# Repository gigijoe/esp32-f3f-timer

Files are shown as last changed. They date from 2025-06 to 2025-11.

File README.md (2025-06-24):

# ESP32 F3F Timer by Steve Chang
This is a open source F3F timer base on ESP32 MCU. It supports wire / wifi / CRSF Base A/B trigger input.
Voice report & external buzzer supoort for minimize delay of audio report.

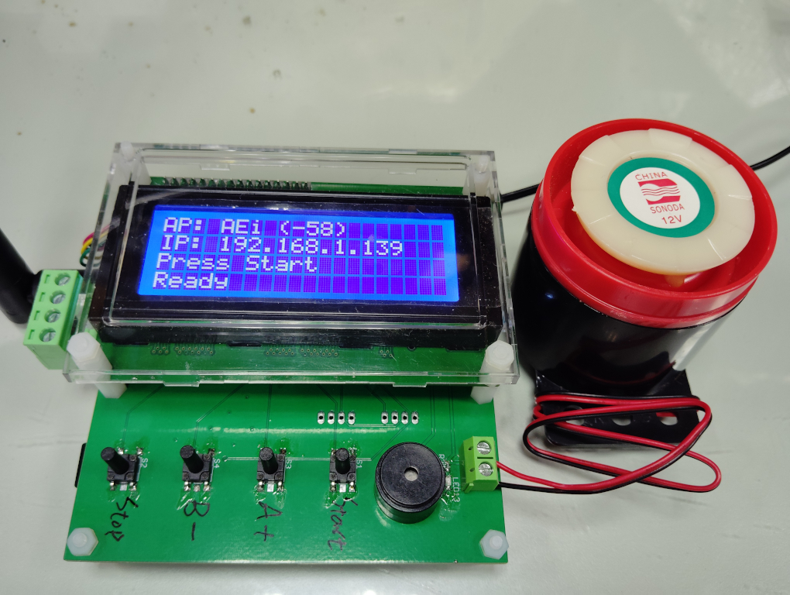
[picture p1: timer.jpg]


### Hardware
- ESP32 MCU
- Micro SD slot
- PCM5102A audio
- Base A/B wire input
- Wifi antenna
- 2004A Mono LCD display
- Internal buzzer / external buzzer
- DC jack 12V
- 4 buttons

### Software
- F3F timer function (Start / Stop / finish / time report)
- Voice report
- Buzzer sound when Base A/B trigger
- Wifi station
- Support wifi multicast trigger from Base A/B
- Support wire Base A/B trigger
- Support CRSF Base A/B trigger
- LCD display Wifi status / timer / volume adjusted / Base A/B trigger

### Buttons
- [ Stop ] / [ B- ] / [ A+ ] / [ Start ] Buttons

## Idle State
- Wifi Status Page
- Last Record Page
- F3F Mode Page - F3F Training / F3F Competition mode switch by [ A+ ] Button
- Wind Data Page
- Volume Page - Adjust volume by [ A+ ] / [ B- ] Buttons

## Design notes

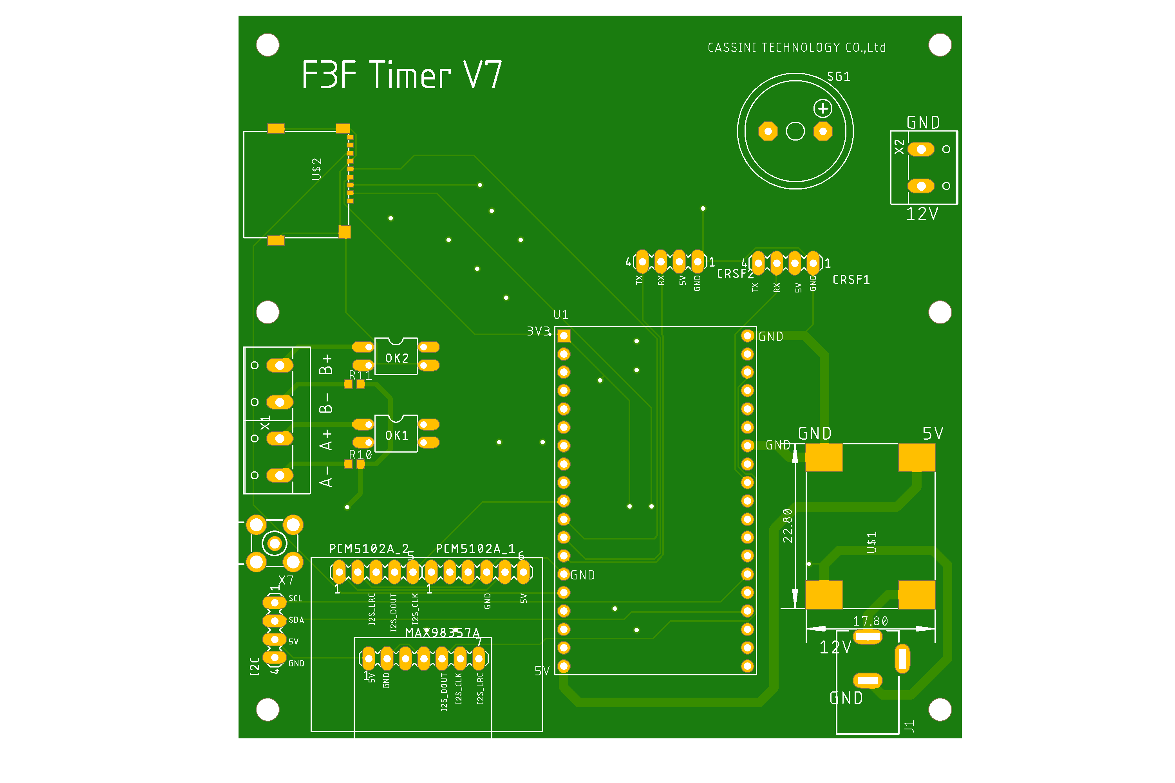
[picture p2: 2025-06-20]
hardware/F3F-TIMER-V7/7.x/top.png

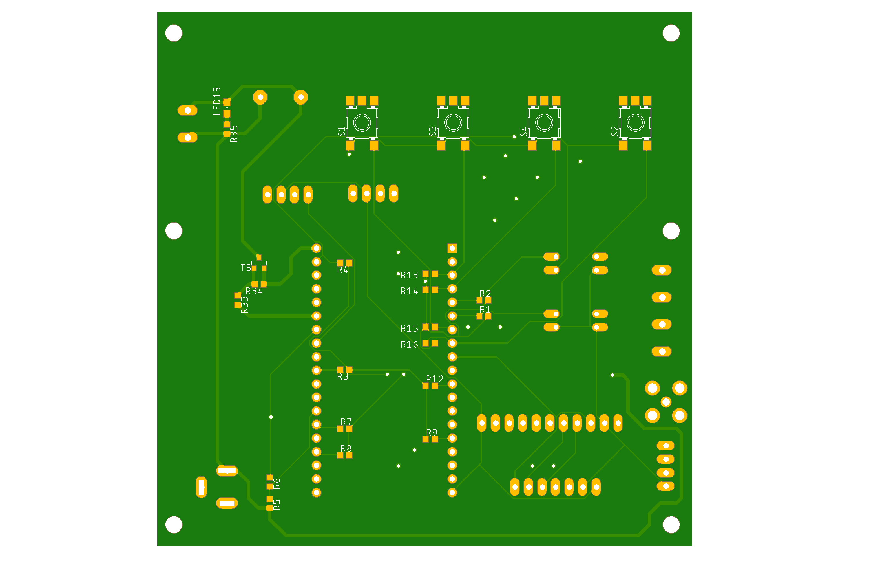
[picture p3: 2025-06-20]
hardware/F3F-TIMER-V7/7.x/bottom.png

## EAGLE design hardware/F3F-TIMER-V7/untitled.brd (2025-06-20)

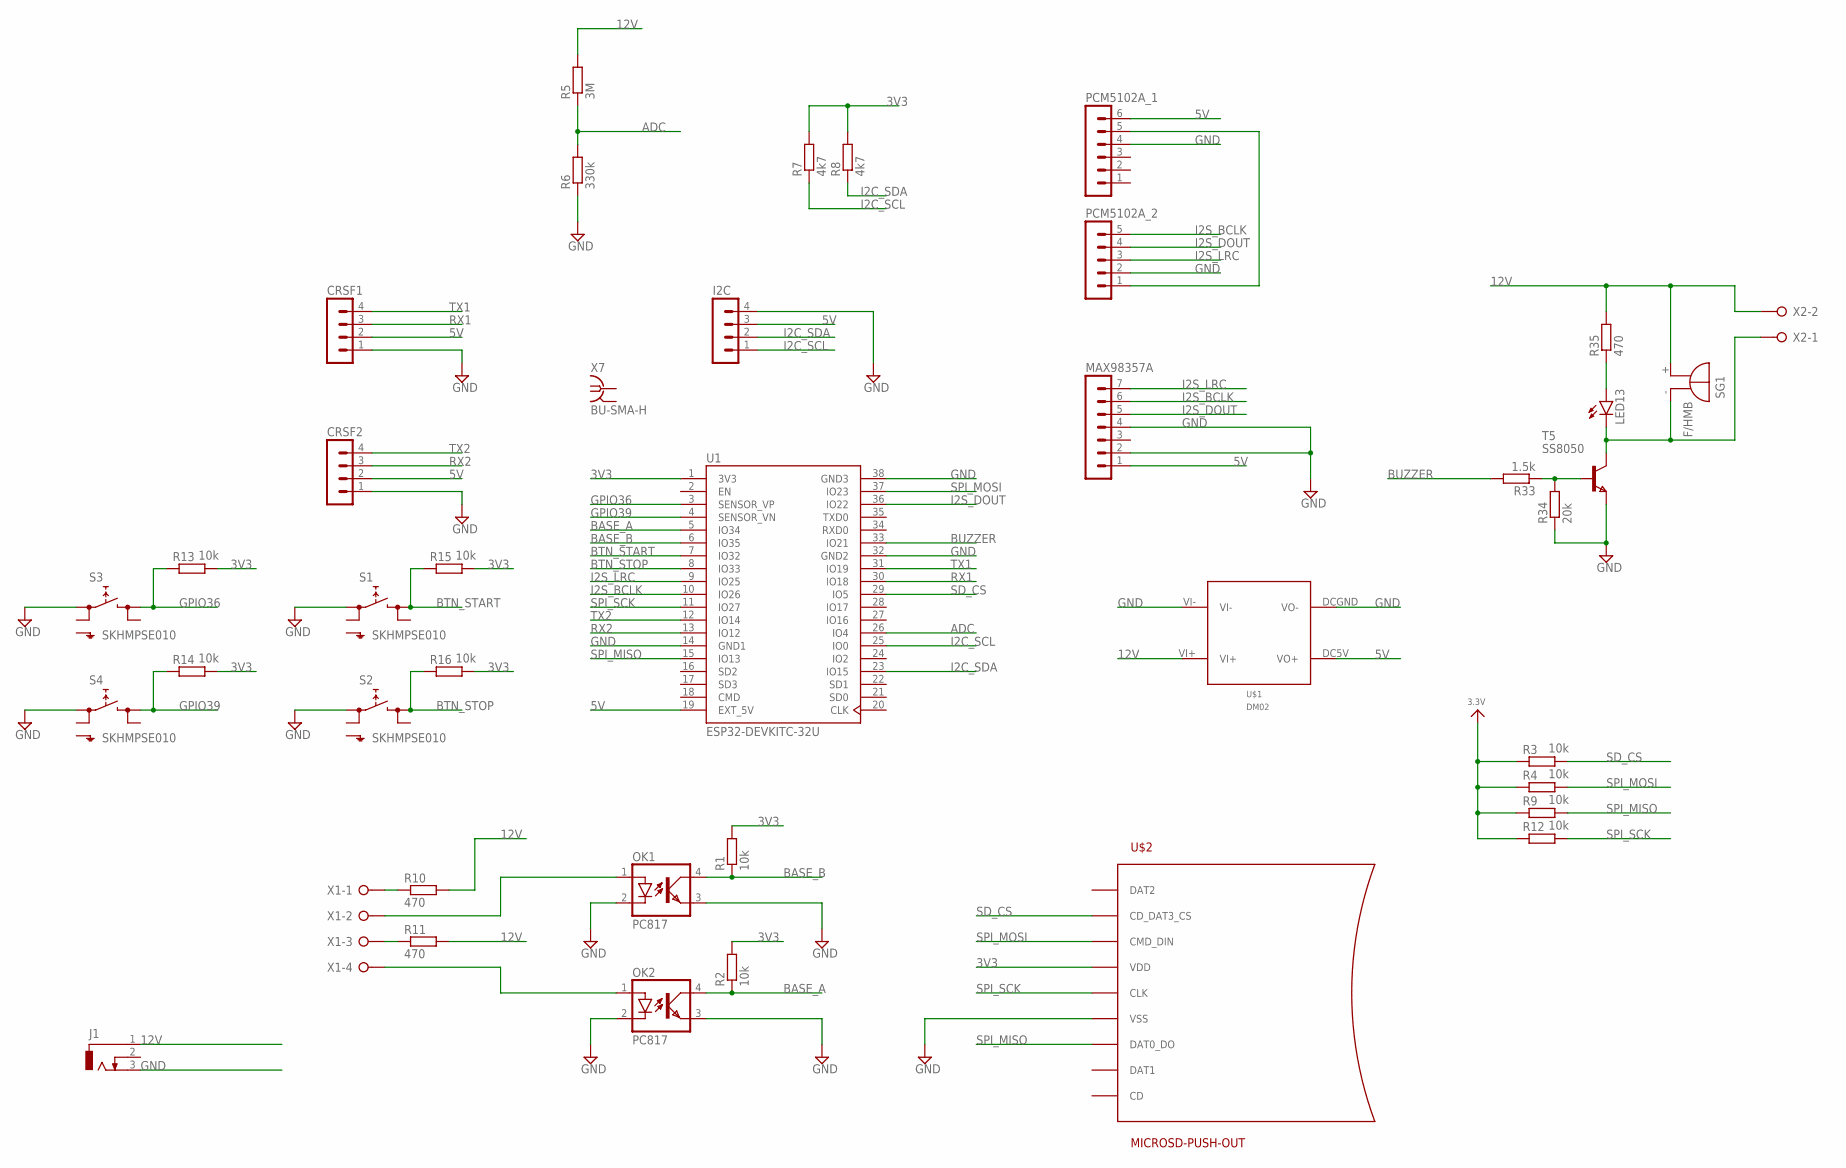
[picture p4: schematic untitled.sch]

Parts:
CRSF1, CRSF2: MA04-1
I2C: MA04-1
J1: DCJ0303
LED13: LEDCHIPLED_0805; CHIPLED_0805
MAX98357A: MA07-1
OK1, OK2: PC817; DIL04
PCM5102A_1: MA06-1
PCM5102A_2: MA05-1
R1, R2, R3, R4, R9, R12, R13, R14, R15, R16: 10k; R0603
R5: 3M; R0603
R6: 330k; R0603
R7, R8: 4k7; R0603
R10, R11, R35: 470; R0603
R33: 1.5k; R0603
R34: 20k; R0603
S1, S2, S3, S4: SKHMPSE010; SKHMPXE010
SG1: F/HMB
T5: SS8050; SOT-23
U1: ESP32-DEVKITC-32U; MODULE_ESP32-DEVKITC-32U
U$1: DM02
U$2: MICROSD-PUSH-OUT
X1: W237-04P; W237-4P
X2: W237-02P; W237-132
X7: BU-SMA-H

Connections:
3.3V: R3.1, R4.1, R9.1, R12.1
3V3: R1.2, R2.2, R7.2, R8.2, R13.2, R14.2, R15.2, R16.2, U1.1 (3V3), U$2.4 (VDD)
5V: CRSF1.2, CRSF2.2, I2C.3, MAX98357A.1, PCM5102A_1.6, U1.19 (EXT_5V), U$1.DC5V (VO+)
12V: J1.1, R5.2, R10.2, R11.2, R35.2, SG1.+, U$1.VI+, X2.2
ADC: R5.1, R6.2, U1.26 (IO4)
BASE_A: OK2.4 (COL), R2.1, U1.5 (IO34)
BASE_B: OK1.4 (COL), R1.1, U1.6 (IO35)
BTN_START: R15.1, S1.3 (2.1), U1.7 (IO32)
BTN_STOP: R16.1, S2.3 (2.1), U1.8 (IO33)
BUZZER: R33.2, U1.33 (IO21)
GND: CRSF1.1, CRSF2.1, I2C.4, J1.3, MAX98357A.2, MAX98357A.4, OK1.2 (C), OK1.3 (EMIT), OK2.2 (C), OK2.3 (EMIT), PCM5102A_1.4, PCM5102A_2.2, R6.1, R34.1, S1.1 (1.1), S2.1 (1.1), S3.1 (1.1), S4.1 (1.1), T5.2 (E), U1.14 (GND1), U1.32 (GND2), U1.38 (GND3), U$1.DCGND (VO-), U$1.VI-, U$2.6 (VSS), U$2.G1 (VSS), U$2.G2 (VSS), U$2.G3 (VSS), U$2.G4 (VSS)
GPIO36: R13.1, S3.3 (2.1), U1.3 (SENSOR_VP)
GPIO39: R14.1, S4.3 (2.1), U1.4 (SENSOR_VN)
I2C_SCL: I2C.1, R7.1, U1.25 (IO0)
I2C_SDA: I2C.2, R8.1, U1.23 (IO15)
I2S_BCLK: MAX98357A.6, PCM5102A_2.5, U1.10 (IO26)
I2S_DOUT: MAX98357A.5, PCM5102A_2.4, U1.36 (IO22)
I2S_LRC: MAX98357A.7, PCM5102A_2.3, U1.9 (IO25)
unnamed: OK1.1 (A), X1.2
unnamed: OK2.1 (A), X1.4
unnamed: PCM5102A_1.5, PCM5102A_2.1
unnamed: R10.1, X1.1
unnamed: R11.1, X1.3
unnamed: R33.1, R34.2, T5.3 (B)
unnamed: LED13.A, R35.1
unnamed: LED13.C, SG1.-, T5.1 (C), X2.1
RX1: CRSF1.3, U1.30 (IO18)
RX2: CRSF2.3, U1.13 (IO12)
SD_CS: R3.2, U1.29 (IO5), U$2.2 (CD_DAT3_CS)
SPI_MISO: R9.2, U1.15 (IO13), U$2.7 (DAT0_DO)
SPI_MOSI: R4.2, U1.37 (IO23), U$2.3 (CMD_DIN)
SPI_SCK: R12.2, U1.11 (IO27), U$2.5 (CLK)
TX1: CRSF1.4, U1.31 (IO19)
TX2: CRSF2.4, U1.12 (IO14)

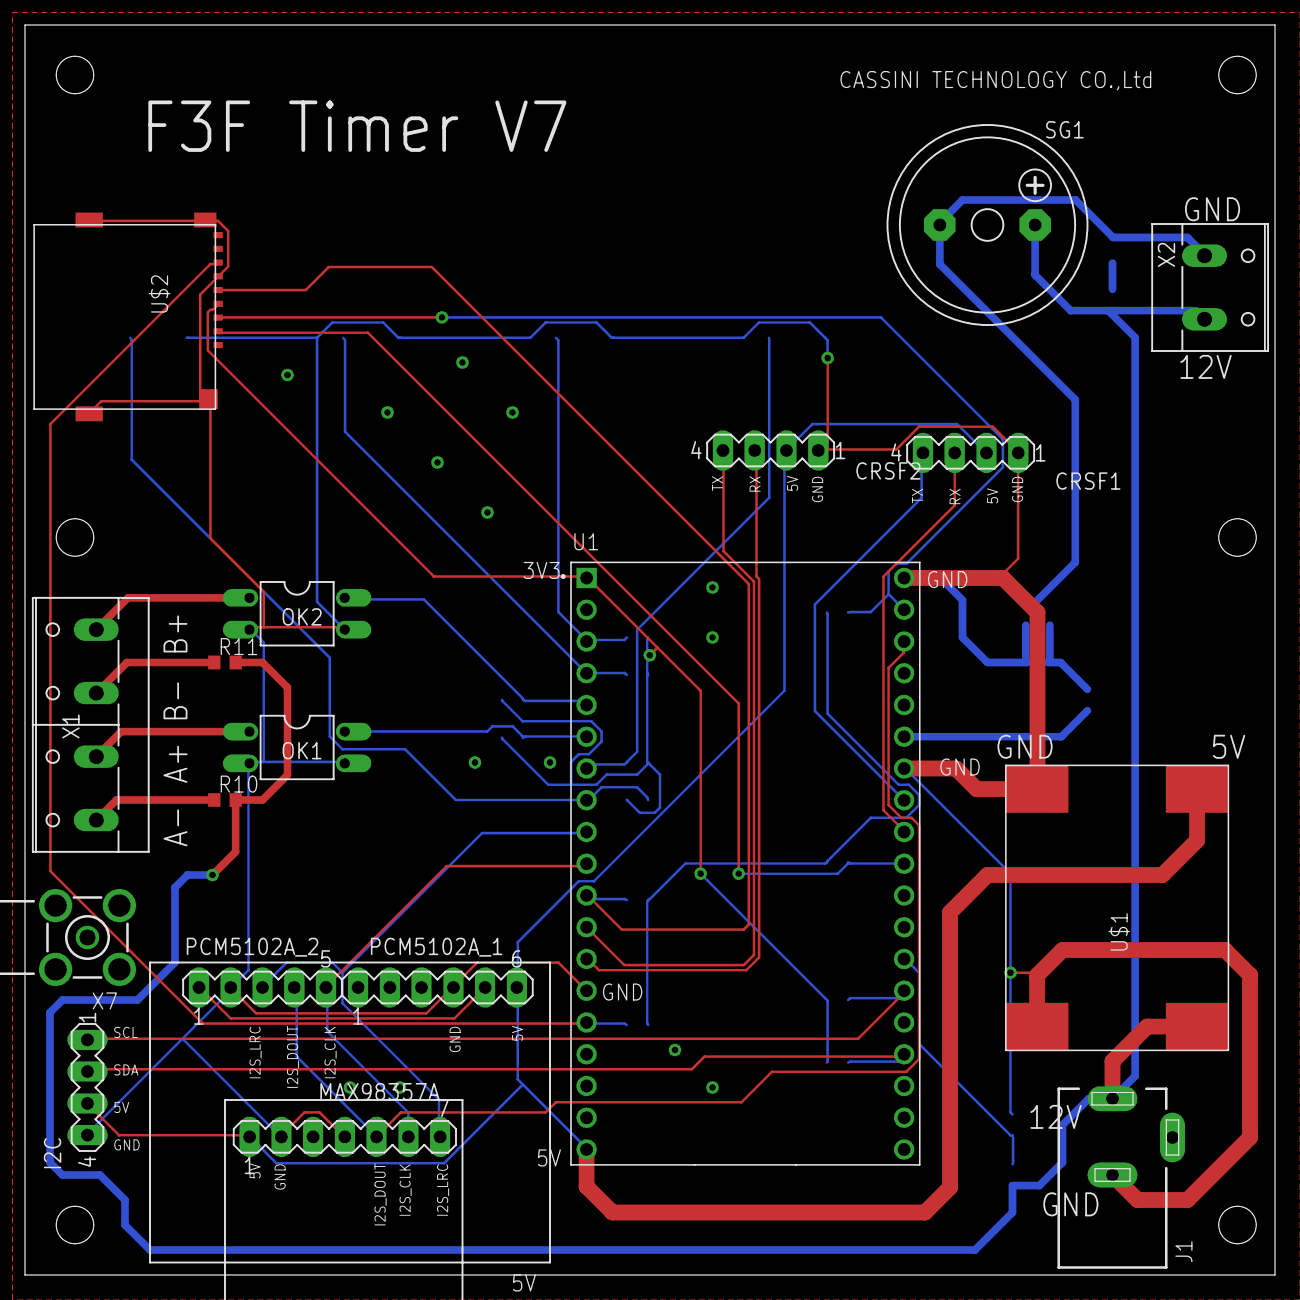
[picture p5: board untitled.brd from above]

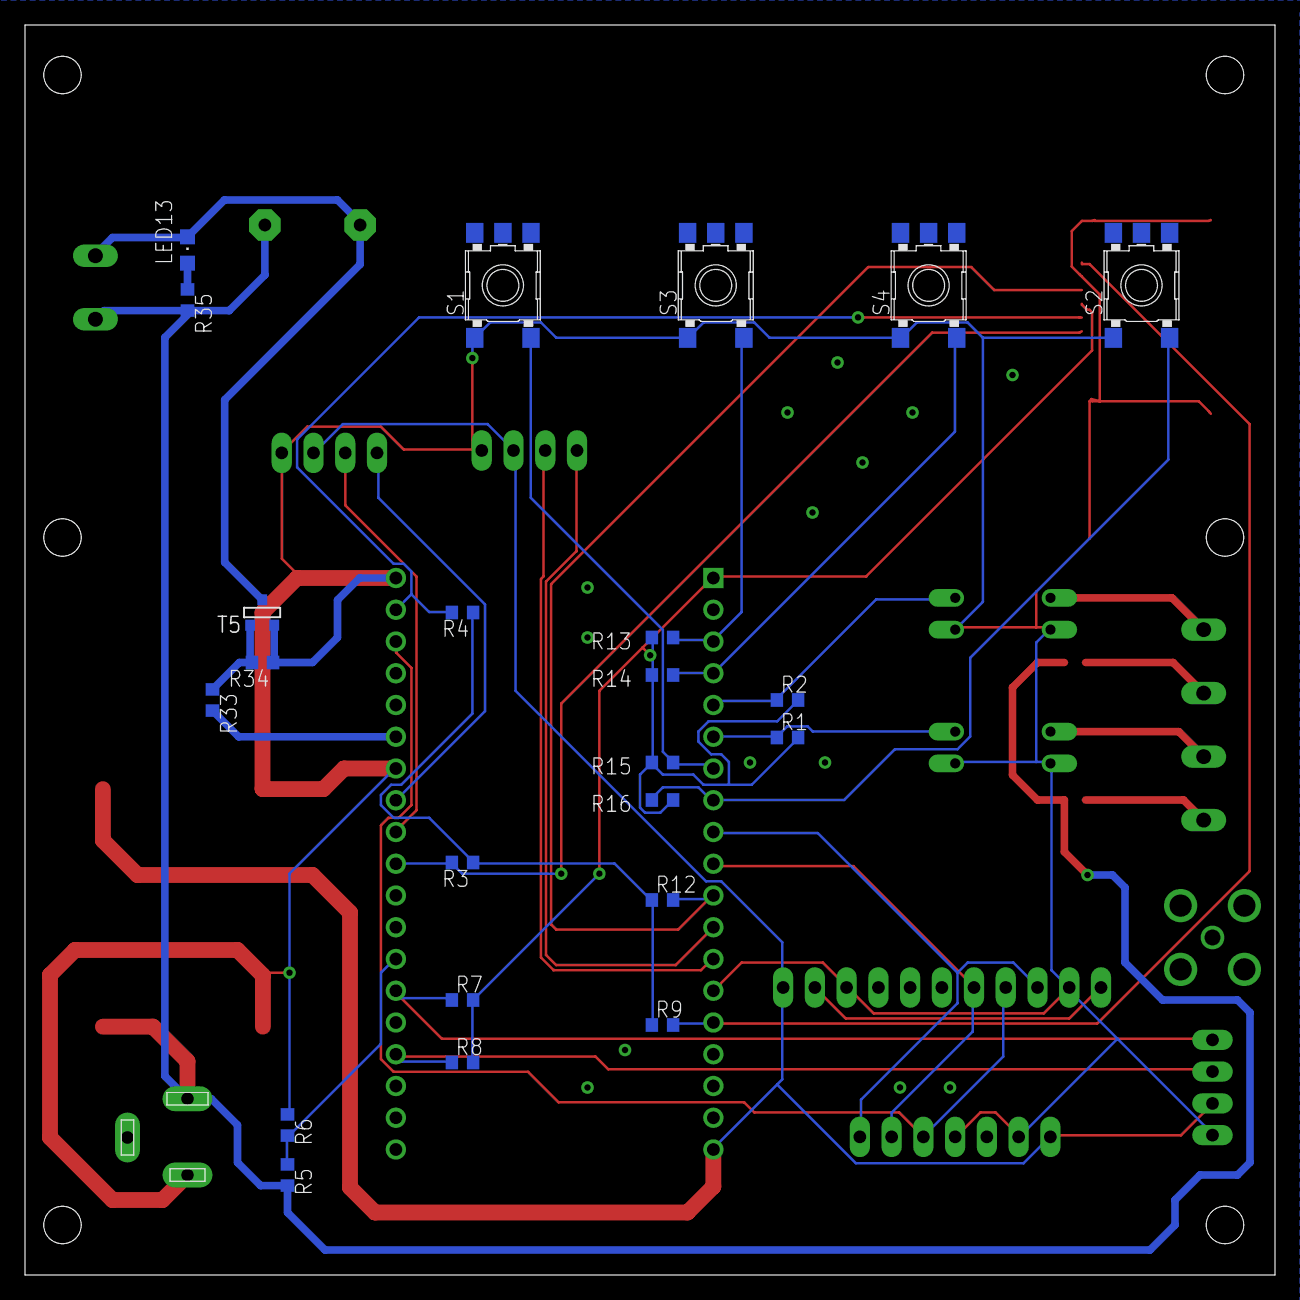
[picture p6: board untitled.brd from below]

Board: 2 copper layers, 100.0 x 100.0 mm, 41 parts (23 on the bottom side), 34 nets.

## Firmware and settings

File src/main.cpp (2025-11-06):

#include <Arduino.h>
#include <SPI.h>
#include <SD.h>
#include "CRSFforArduino.hpp"
#include "player.h"
#include "lcd204.h"
#include "f3f.h"

#define BUZZER 21

void buzzerSetup() {
  pinMode(BUZZER, OUTPUT);
  digitalWrite(BUZZER, LOW);
}

static uint32_t buzzerTime = 0;
void buzzerStart()
{
  buzzerTime = millis();
  digitalWrite(BUZZER, HIGH);
}

void buzzerLoop()
{
  if(buzzerTime == 0)
    return;
  if(millis() - buzzerTime > 100) {
    digitalWrite(BUZZER, LOW);
    buzzerTime = 0;
  }
}

HardwareSerial teleBusA = HardwareSerial(1);
HardwareSerial teleBusB = HardwareSerial(2);

CRSFforArduino crsfA = CRSFforArduino(&teleBusA, 18, 19);
//CRSFforArduino crsfB = CRSFforArduino(&teleBusB, 16, 17);
CRSFforArduino crsfB = CRSFforArduino(&teleBusB, 12, 14);

uint32_t serNoA = 0;
uint32_t serNoB = 0;

// microSD Card Reader connections
#define SD_CS          5
#define SPI_MOSI      23 
#define SPI_MISO      13
#define SPI_SCK       27

/*
* CRSF
*/

void crsfSetup()
{
    Serial.println("CRSF setup");

    /* Initialise CRSF for Arduino */
    if (!crsfA.begin()) {
      Serial.println("CRSF A initialization failed!");
        return;
    }

    if (!crsfB.begin()) {
      Serial.println("CRSF B initialization failed!");
        return;
    }

    /* Show the user that the sketch is ready. */
    Serial.println("Ready");
    //delay(1000);
}

#define VIEW_RC_CHANNELS 0

#if VIEW_RC_CHANNELS > 0
const int channelCount = 8;
const char *channelNames[crsfProtocol::RC_CHANNEL_COUNT] = {
    "A", "E", "T", "R", "Aux1", "Aux2", "Aux3", "Aux4", "Aux5", "Aux6", "Aux7", "Aux8", "Aux9", "Aux10", "Aux11", "Aux12"};

static_assert(channelCount <= crsfProtocol::RC_CHANNEL_COUNT, "The number of RC channels must be less than or equal to the maximum number of RC channels supported by CRSF.");
#endif

void crsfLoop()
{
/* Call crsf.update() in the main loop to process CRSF packets. */
crsfA.update();
/* Call crsf.update() in the main loop to process CRSF packets. */
crsfB.update();

#if VIEW_RC_CHANNELS > 0  
    // Use timeNow to store the current time in milliseconds.
    uint32_t timeNow = millis();

/* You can process RC channel data here. */

    static unsigned long lastPrint = 0;
    if (timeNow - lastPrint >= 100)
    {
        lastPrint = timeNow;
        Serial.print("Base A Channels <");
        for (uint8_t i = 0; i < channelCount; i++)
        {
          Serial.print(channelNames[i]);
          Serial.print(": ");
          Serial.print(crsfA.rcToUs(crsfA.getChannel(i + 1)));
            if (i < channelCount - 1)
            {
              Serial.print(", ");
            }
        }
        Serial.println(">");

        lastPrint = timeNow;
        Serial.print("Base B Channels <");
        for (uint8_t i = 0; i < channelCount; i++)
        {
          Serial.print(channelNames[i]);
          Serial.print(": ");
          Serial.print(crsfB.rcToUs(crsfB.getChannel(i + 1)));
            if (i < channelCount - 1)
            {
              Serial.print(", ");
            }
        }
        Serial.println(">");        
    }
#else
    // Use timeNow to store the current time in milliseconds.
    uint32_t timeNow = millis();

    static unsigned long lastPrint = 0;
    if (timeNow - lastPrint >= 300)
    {
      if(crsfA.rcToUs(crsfA.getChannel(1)) == 2000) {
        Serial.printf("<A%04u>\r\n", serNoA % 10000);
        F3F_TiggleBaseA(serNoA++);
        yield();
        //buzzerStart();
      }

      if(crsfB.rcToUs(crsfB.getChannel(1)) == 2000) {
        Serial.printf("<B%04u>\r\n", serNoB % 10000);
        F3F_TiggleBaseB(serNoB++);
        yield();
        //buzzerStart();
      }
      lastPrint = timeNow;
    }
#endif
}

/*
* Multicast UDP
*/

#include "WiFi.h"
#include "AsyncUDP.h"

AsyncUDP udp;

const char *ssid[] = {"F3F-AP-N", "F3F-AP-AC", "AEi"};
const char *password[] = {"0925322362", "0925322362", "0226962665"};
static uint8_t apIndex = 0;

void WiFiStationConnected(WiFiEvent_t event, WiFiEventInfo_t info)
{
  Serial.println("Connected to AP successfully!");
}
 
HeadLineType s_headLine = showCpuUsage;

void WiFiGotIP(WiFiEvent_t event, WiFiEventInfo_t info)
{
  Serial.println("WiFi connected");
  Serial.print("IP address: ");
  Serial.println(WiFi.localIP());

  // print the SSID of the network you're attached to:
  Serial.print("SSID: ");
  Serial.println(WiFi.SSID());

  if(s_headLine == showCpuUsage) {
    lcdPrintRow(0, "AP: %s (%d)", WiFi.SSID(), WiFi.RSSI());
    lcdPrintRow(1, "IP: %s", WiFi.localIP().toString());
  }
  // print the MAC address of the router you're attached to:
  byte bssid[6];
  WiFi.BSSID(bssid);
  Serial.print("BSSID: ");
  Serial.print(bssid[5], HEX);
  Serial.print(":");
  Serial.print(bssid[4], HEX);
  Serial.print(":");
  Serial.print(bssid[3], HEX);
  Serial.print(":");
  Serial.print(bssid[2], HEX);
  Serial.print(":");
  Serial.print(bssid[1], HEX);
  Serial.print(":");
  Serial.println(bssid[0], HEX);

  // print the received signal strength:
  long rssi = WiFi.RSSI();
  Serial.print("signal strength (RSSI):");
  Serial.println(rssi);

  // print the encryption type:
  byte encryption = WiFi.encryptionType(0);
  Serial.print("Encryption Type:");
  Serial.println(encryption, HEX);
  Serial.println();

  if (udp.listenMulticast(IPAddress(224, 0, 0, 3), 9003)) {
    Serial.print("UDP Listening on IP: ");
    Serial.println(WiFi.localIP());
    udp.onPacket([](AsyncUDPPacket packet) {
      if (packet.isMulticast()) {  // <<<====   Only listen to Multicasting Messages
#if 0
        Serial.print("UDP Packet Type: Multicast");
        Serial.print(", From: ");
        Serial.print(packet.remoteIP());
        Serial.print(":");
        Serial.print(packet.remotePort());
        Serial.print(", To: ");
        Serial.print(packet.localIP());
        Serial.print(":");
        Serial.print(packet.localPort());
        Serial.print(", Length: ");
        Serial.print(packet.length());
        Serial.print(", Data: ");
        Serial.write(packet.data(), packet.length());
        Serial.println();
#endif
        uint8_t *p = packet.data();
        if(p[0] == '<' && p[6] == '>') {
          if(p[1] == 'A') {
            uint8_t buf[5];
            memcpy(buf, &p[2], 4);
            buf[4] = 0;
            uint32_t serNo = atoi((const char *)buf) % 10000;
            if(serNo != serNoA) {
              //buzzerStart();
              F3F_TiggleBaseA(serNo);
              yield();
              serNoA = serNo;              
            }
          } else if(p[1] == 'B') {
            uint8_t buf[5];
            memcpy(buf, &p[2], 4);
            buf[4] = 0;
            uint32_t serNo = atoi((const char *)buf) % 10000;
            if(serNo != serNoB) {
              //buzzerStart();
              F3F_TiggleBaseB(serNo);
              yield();
              serNoB = serNo;
            }
          }
        }
      }
    });    
  }
}
 
void WiFiStationDisconnected(WiFiEvent_t event, WiFiEventInfo_t info)
{
  Serial.print("Disconnected from WiFi AP ");
  Serial.println(WiFi.SSID());
  Serial.print("WiFi lost connection. Reason: ");
  Serial.println(info.wifi_sta_disconnected.reason);

  //lcdPrintRow(1, "%d", info.wifi_sta_disconnected.reason);

  apIndex++;
  if(apIndex >= sizeof(ssid) / sizeof(ssid[0]))
    apIndex = 0;
  
  Serial.print("Trying to connect AP ");
  Serial.println(ssid[apIndex]);
  //WiFi.begin(ssid[apIndex], password[apIndex]);
  WiFi.STA.connect(ssid[apIndex], password[apIndex]);

  if(s_headLine == showCpuUsage) {
    lcdPrintRow(0, "AP: %s", ssid[apIndex]);
    lcdPrintRow(1, "Connecting ...");
  }
}

void mcastSetup()
{
  Serial.begin(115200);
  WiFi.disconnect(true);
  delay(1000);
 
  WiFi.onEvent(WiFiStationConnected, WiFiEvent_t::ARDUINO_EVENT_WIFI_STA_CONNECTED);
  WiFi.onEvent(WiFiGotIP, WiFiEvent_t::ARDUINO_EVENT_WIFI_STA_GOT_IP);
  WiFi.onEvent(WiFiStationDisconnected, WiFiEvent_t::ARDUINO_EVENT_WIFI_STA_DISCONNECTED);

  /* Remove WiFi event
  Serial.print("WiFi Event ID: ");
  Serial.println(eventID);
  WiFi.removeEvent(eventID);*/
  WiFi.STA.begin();
  //WiFi.begin(ssid[apIndex], password[apIndex]);

  if(!WiFi.STA.waitStatusBits(ESP_NETIF_STARTED_BIT, 10000)){
    Serial.println("Failed to start WiFi!");
  }
  WiFi.setTxPower(WIFI_POWER_19_5dBm); // Maximum WIFI_POWER_19_5dBm
  int pwr = WiFi.getTxPower();
  Serial.printf("TX Power: %.1fdBm\n", pwr * 0.25);

#if 0
  Serial.println("WiFi scan start");

  // WiFi.scanNetworks will return the number of networks found
  int n = WiFi.scanNetworks();
  Serial.println("Scan done");
  if (n == 0) {
      Serial.println("No networks found");
  } else {
      Serial.print(n);
      Serial.println(" networks found");
      for (int i = 0; i < n; ++i) {
          // Print SSID and RSSI for each network found
          Serial.print(i + 1);
          Serial.print(": ");
          Serial.print(WiFi.SSID(i));
          Serial.print(" (");
          Serial.print(WiFi.RSSI(i));
          Serial.print(")");
          Serial.println((WiFi.encryptionType(i) == WIFI_AUTH_OPEN)?" ":"*");
          
          String net = WiFi.SSID(i);            
          for (int x = 0; x < net.length(); ++x){
            Serial.print((int)net[x]);
            Serial.print(" ");
          }
          Serial.println("\n----------");
      }
  }
  Serial.println("");
#endif

  WiFi.STA.connect(ssid[apIndex], password[apIndex]);

  if(s_headLine == showCpuUsage) {
    lcdPrintRow(0, "AP: %s", ssid[apIndex]);
    lcdPrintRow(1, "Connecting ...");
  }

  Serial.println();
  Serial.println();
  Serial.println("Wait for WiFi... ");
}

void mcastLoop(){
  static uint32_t lastTime = 0;
  if(WiFi.status() == WL_CONNECTED) {
    if(millis() - lastTime >= 1000) {
      if(s_headLine == showCpuUsage)
        lcdPrintRow(0, "AP: %s (%d)", WiFi.SSID(), WiFi.RSSI());
      lastTime = millis();
    }
  }
}

/*
* F3F
*/

/*
hw_timer_t *  timer1 = NULL;
portMUX_TYPE  timerMux1 = portMUX_INITIALIZER_UNLOCKED;

void IRAM_ATTR onTimer1() {
  portENTER_CRITICAL_ISR(&timerMux1);
  portEXIT_CRITICAL_ISR(&timerMux1);
}
*/

#define BTN_START 32
#define BTN_A 36
#define BTN_B 39
#define BTN_STOP 33

#define BASE_A 34
#define BASE_B 35

void setup() {
  // Set microSD Card CS as OUTPUT and set HIGH
  pinMode(SD_CS, OUTPUT);      
  digitalWrite(SD_CS, HIGH); 

  pinMode(BTN_START, INPUT_PULLUP);      //input pull-up resistor is enabled
  pinMode(BTN_A, INPUT);
  pinMode(BTN_B, INPUT);
  pinMode(BTN_STOP, INPUT_PULLUP);      //input pull-up resistor is enabled

  pinMode(BASE_A, INPUT);      //input pull-up resistor is enabled
  pinMode(BASE_B, INPUT);

/* 
  timer1 = timerBegin(1000);               // 1k Hz
	timerAttachInterrupt(timer1, &onTimer1);   // attach handler, trigger on edge 
	timerAlarm(timer1, 1000L, true, 0);            // 1000 * 1us = 1ms, single shot
*/
  Serial.begin(115200);

  lcd2004Setup();

  // Initialize SPI bus for microSD Card
  SPI.begin(SPI_SCK, SPI_MISO, SPI_MOSI);  
  // Start microSD Card
  if(!SD.begin(SD_CS, SPI, 40000000))
  {
    Serial.println("Error accessing microSD card!");
    lcdPrintRow(1, "  !!! SD Error !!!  ");
    while(true); 
  }

  crsfSetup();
  buzzerSetup();
  mcastSetup();

  F3F_Init([](HeadLineType type) {
    s_headLine = type;
    switch(type) {
      case showCpuUsage:
        if(WiFi.status() == WL_CONNECTED) {
          lcdPrintRow(0, "AP: %s (%d)", WiFi.SSID(), WiFi.RSSI());
          lcdPrintRow(1, "IP: %s", WiFi.localIP().toString());        
        }
        break;
      case showLastRecord:
        lcdPrintRow(0, "Last record %s", F3F_LastRecord());
        break;
      case showF3fMode:
        switch(F3F_Mode()) {
          case f3fCompetition:  lcdPrintRow(0, "F3F Competition");
            break;
          case f3fTraining: lcdPrintRow(0, "F3F Training");
            break;
        }
        break;
      case showWindData:
        lcdPrintRow(0, "Wind speed & range  ");
        break;
      case showVolume: 
        lcdPrintRow(0, "Volume : %d dbm", Mp3Player_GetVolume());
        break;
      default:
        break;
    }
  });

  xTaskCreatePinnedToCore(
    F3F_Task,      // Function that should be called
    "F3F_Task",    // Name of the task (for debugging)
    8192,               // Stack size (bytes)
    NULL,               // Parameter to pass
    (configMAX_PRIORITIES -1),                  // Task priority
    NULL,               // Task handle
    1          // Core you want to run the task on (0 or 1)
  );
}

void loop() {
  if(digitalRead(BTN_START) == LOW) {
    F3F_KeyStart();
    //buzzerStart();
  }

  if(digitalRead(BTN_A) == LOW) {
    F3F_KeyA();
    //buzzerStart();
  }

  if(digitalRead(BTN_B) == LOW) {
    F3F_KeyB();
    //buzzerStart();
  }

  if(digitalRead(BTN_STOP) == LOW) {
    F3F_KeyStop();
    //buzzerStart();
  }

  if(digitalRead(BASE_A) == LOW) {
    //buzzerStart();
    F3F_KeyBaseA();
    yield();
  }

  if(digitalRead(BASE_B) == LOW) {
    //buzzerStart();
    F3F_KeyBaseB();
    yield();
  }

  lcd2004Loop();
  crsfLoop();
  mcastLoop();
  buzzerLoop();
}
/*
void audio_info(const char *info){
  Serial.print("info        "); Serial.println(info);
}
*/

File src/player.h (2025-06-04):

#ifndef PLAYER_H
#define PLAYER_H

#include <stdint.h>

// I2S Connections
#define I2S_DOUT      22
#define I2S_BCLK      26
#define I2S_LRC       25

void Mp3Player_Init(void);
void Mp3Player_Loop(void);

void Mp3Player_Play(const char *filePath);
void Mp3Player_PlayPriority(const char *filePath);
void Mp3Player_Stop(void);
void Mp3Player_Reset(void);
bool Mp3Player_IsPlaying(void);
const char *Mp3Player_CurrentPlayFile();

uint8_t Mp3Player_GetVolume();
void Mp3Player_SetVolume(uint8_t volume);

#endif

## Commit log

2025-06-20 1.Fix Base trigger UI display bug 2.Set audio volume level to 21 3.Add README.md
    [main.cpp, player.cpp]
2025-06-20 Add hardware
    [untitled.brd, untitled.sch]
2025-06-24 Add timer jpg

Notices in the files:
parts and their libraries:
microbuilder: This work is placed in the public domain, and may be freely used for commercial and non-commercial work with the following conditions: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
